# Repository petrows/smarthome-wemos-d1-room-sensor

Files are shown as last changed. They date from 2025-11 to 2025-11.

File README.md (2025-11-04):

# GALOPED: Simple room sensor, Tasmota-ready

Device image

This project designed to provide some simple-to-repeat, WiFi DIY sensor with features:

* Telemetry to Smarthome systems: CO2 level, Temperature, Humidity and Pressure
* Runs Tasmota out-of-the-box, no DIY firmware required, all Tasmota features are on place (WebUI, MQTT, etc)
* Uses cheap Wemos-D1 board as CPU and WiFi
* Do not require SMD components installation, can be assembled with regural solder
* Simple construction, can be used as learning project
* Powered by USB from module (you can use variants with USB-C or Mini USB)
* Optional external power via terminal block
* Uses hi-precision climate sensor module
* Has three LED's, can bu used to display current CO2 level, as well as for any other purpose

## Assembly

What you need to build this device:

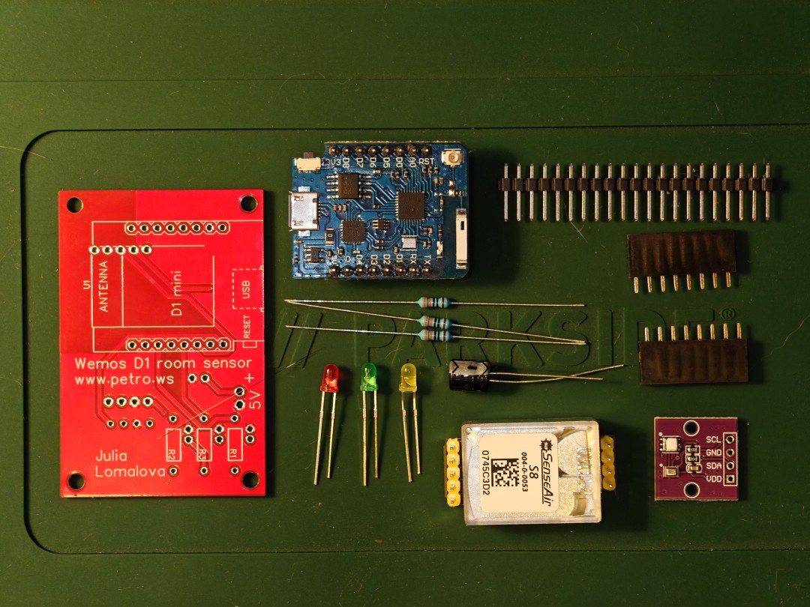
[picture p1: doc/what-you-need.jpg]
What you need


[Detailed assembly instructions](README.Assembly.md).

Required components are:

* PCB board (TBD), ~2€
* Wemos D1 mini / pro board. You can use any kind of this device, using USB-C or classical Mini-USB, [Aliexpress](https://de.aliexpress.com/item/1005001621784437.html), ~5€
* SenseAIR S8 device, original or any of its clones, [Aliexpress](https://de.aliexpress.com/item/1005004123170360.html), ~30€
* AHT20+BMP280 Temperature Humidity Air Pressure Module, [Aliexpress](https://de.aliexpress.com/item/1005005486181411.html), ~3€
* 330R wired resistors, 3 pcs, ~1€
* 3mm LED's, color on your with, 3 pcs, ~1€
* Electrolytic capacitor, suitable any rated 10+ V and 300+ Mf, ~1€
* Common 2.54mm pin headers: male and female, ~1€

Total components price: ~44€

All elements, except MCU and PCB borad are *optional*. Device can be also assembled as CO²-only or Temperature-only device, with and without indication, as well as bare MCU on board. Missing components will not prevent device to run normally, in case of missing components you will not get telemetry data.

**Board is designed to fit into standart 60x60 mm electric box**. I use it at my home to meausre outside temperature (CO² sensor and LED's are not installed).

Electric box version

## PCB Borad

Hardware project page: https://oshwlab.com/petrows/wemos-d1-room-sensor

PCB can be purchased directly from Project page.

## Firmware

Download here: https://github.com/petrows/smarthome-galoped/releases

Regarding flashing / config / recompile: see below

## Case

There is a case for 3D print provided. Files can be found under `3d-case` folder. Model published on [thingiverse.com website](https://www.thingiverse.com/thing:7191151).

> **WARNING**: to use this device within closed case, check and apply calibration. ESP and S8 sensors going warm during work, and it will affect tempterature sensor.

Recommended calibration for this case: `-4 C°`. To apply calibration, navigate to `Console` and type in command:

```
TempOffset -4
```

It is anyway recommended to calibrate your sensor, especially if purchasing some random components on Aliexpress.

## Led display level

LED's are actually GPIO's (connected as Relays in Tasmota), can be triggered via API / MQTT / etc as usial switches.

Provided firmware (see below) has rule activated by default. You may activate it by calling commands:

```
Rule1 "ON S8#CarbonDioxide<800 DO Power3 1 BREAK ON S8#CarbonDioxide<1500 DO Power2 1 BREAK ON S8#CarbonDioxide>0 DO Power1 1 ENDON"
Rule1 ON
```

This will enable fully offline LED indication. In default rules, they will display GREEN below 800, YELLOW below 1500 and RED otherwise. You can find and adjust this levels in `Rule1` command.

If you dont need this rule, you can deactivate it via:

```
Rule1 OFF
```

## Tasmota config

To configure module, you have to use custom firmware, as Tasmota has ANTx sensors support [disabled by default](https://tasmota.github.io/docs/AHT2x/).

Simple workflow to upload proper firmware:

```bash
wget https://petro.ws/s/tasmota-15.1.0-pws-module-v2.bin -O tasmota.bin
esptool erase_flash
esptool write_flash -fm dout 0x0 tasmota.bin
```

Then configure Tasmota as usial, by connecting to built-in WiFI AP.

Next step is to apply template. Navigate to `Configuration` » `Other`. There in `Template` section paste template:
```json
{"NAME":"PWS-Room-v2","GPIO":[1,1,1,1,608,640,1,1,224,1632,225,1600,226,1],"FLAG":0,"BASE":18,"CMND":"Interlock 1|WebButton1 R | WebButton2 Y | WebButton3 G | Rule1 ON"}
```
Enable `Activate` checkbox. Press `Save` to apply template.

Connect you sensors back and now you will see data from sensors read:

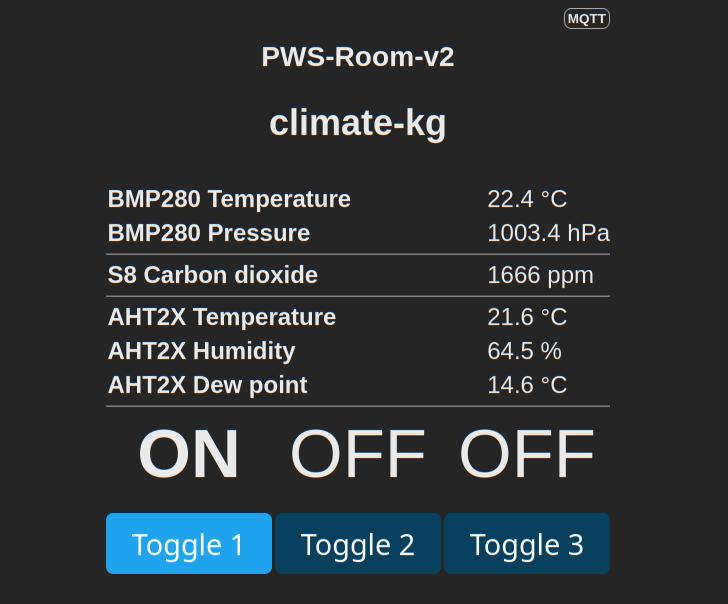
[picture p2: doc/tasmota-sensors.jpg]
Sensors data example


## Compile firmware

Prepare environment first.
Note: important to use same console, as it uses virtual environment activated.
All commands should be executed from repo root.

```bash
# Prepare Python env
python -m venv build/venv
source build/venv/bin/activate
# Install PlatformIO
pip install -U platformio
git clone https://github.com/arendst/Tasmota.git build/tasmota
```

Select release, what you want to use as a base:
```bash
cd build/tasmota
git checkout v15.1.0
```

Copy overrides config, where we have proper sensors enabled:
```bash
cp user_config_override.h build/tasmota/tasmota/
```

Now you can compile firmware. Replace upload port with your own:
```bash
cd build/tasmota
platformio run -e tasmota --target upload --upload-port /dev/ttyUSB0
```

Precompiled firmware can be found under `.pio/build/tasmota/firmware.bin`.

Precompiled firmwares could be found here: https://github.com/petrows/smarthome-galoped/releases

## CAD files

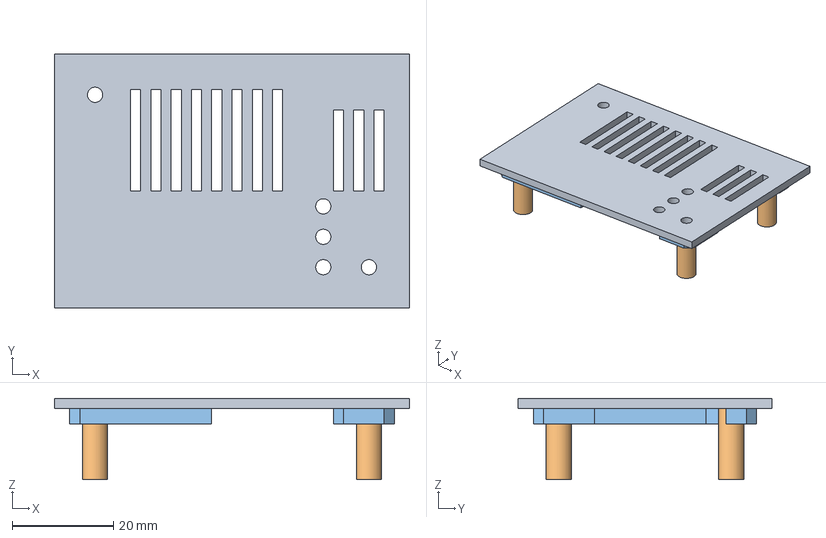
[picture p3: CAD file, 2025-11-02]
3d-case/smarthome-wemos-d1-room-sensor-case-up.FCStd
70.0 x 50.0 x 16.0 mm
Holders

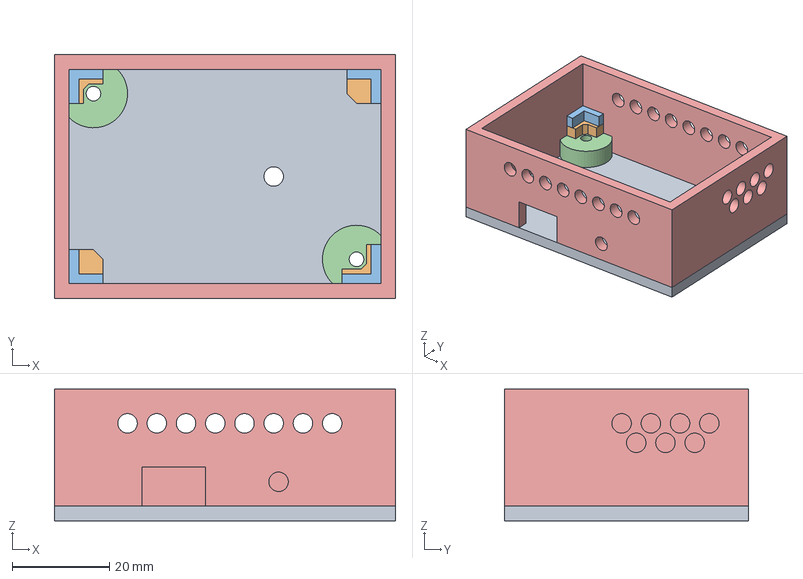
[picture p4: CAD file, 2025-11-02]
3d-case/smarthome-wemos-d1-room-sensor-case-down.FCStd
70.0 x 50.0 x 27.0 mm
Bottom
Board-support
Board-corners001
Nuts-base001

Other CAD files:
3d-case/smarthome-wemos-d1-room-sensor-case-board.FCStd
3d-case/smarthome-wemos-d1-room-sensor-case-down.stl
3d-case/smarthome-wemos-d1-room-sensor-case-up.stl

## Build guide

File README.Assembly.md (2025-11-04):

# Assembly instructions

First, prepare what you need:

What you need

## PCB passive components assembly

First of all, select *female* pinheads and cut off them to: 2x 4-pin and 1x 5-pin.

Solder them to marked places into S8 and ANT20 modules as folows:

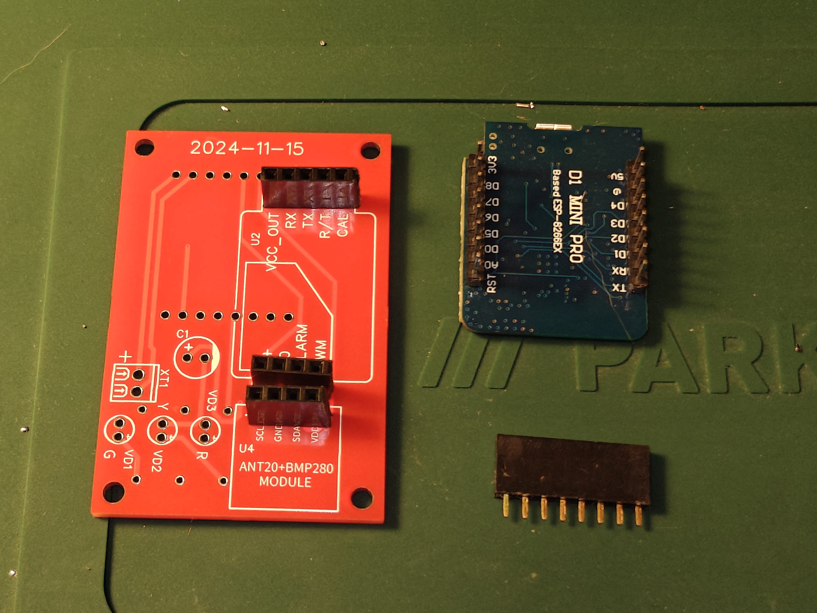
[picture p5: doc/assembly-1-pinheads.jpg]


**WARNING**: Test your solder quality with tester! Futher fixes will be hard to do, as solder points will be covered by MCU on next steps!

Install capacitor on the marked place:

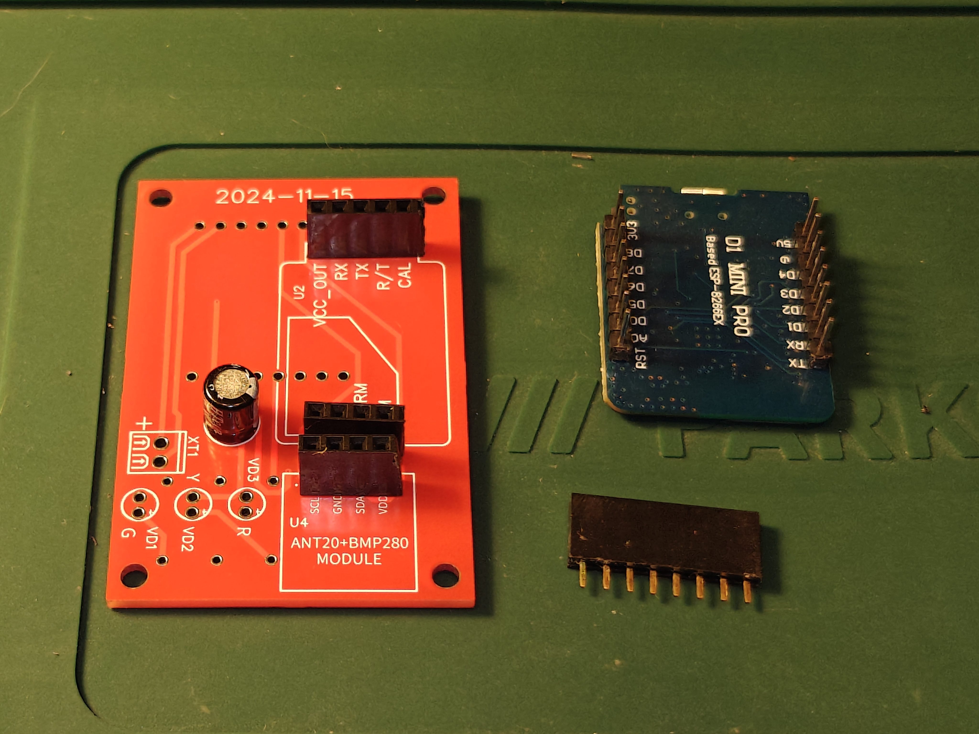
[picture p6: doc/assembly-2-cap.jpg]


Install LED limiting resisors on the marked place:

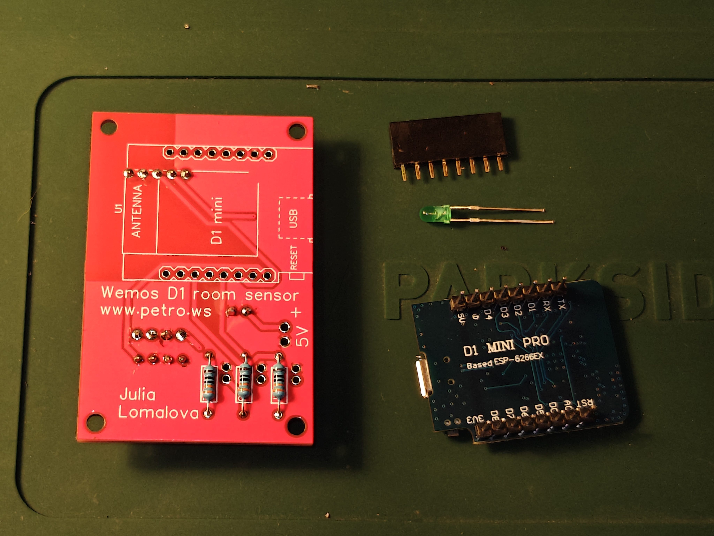
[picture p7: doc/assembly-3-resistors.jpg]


Prepare LED's. To use within provided case, they have to be with 13 mm offcet from board. One of possible way to fit this distance: cut off the isolation tube in advance, and use it on install:

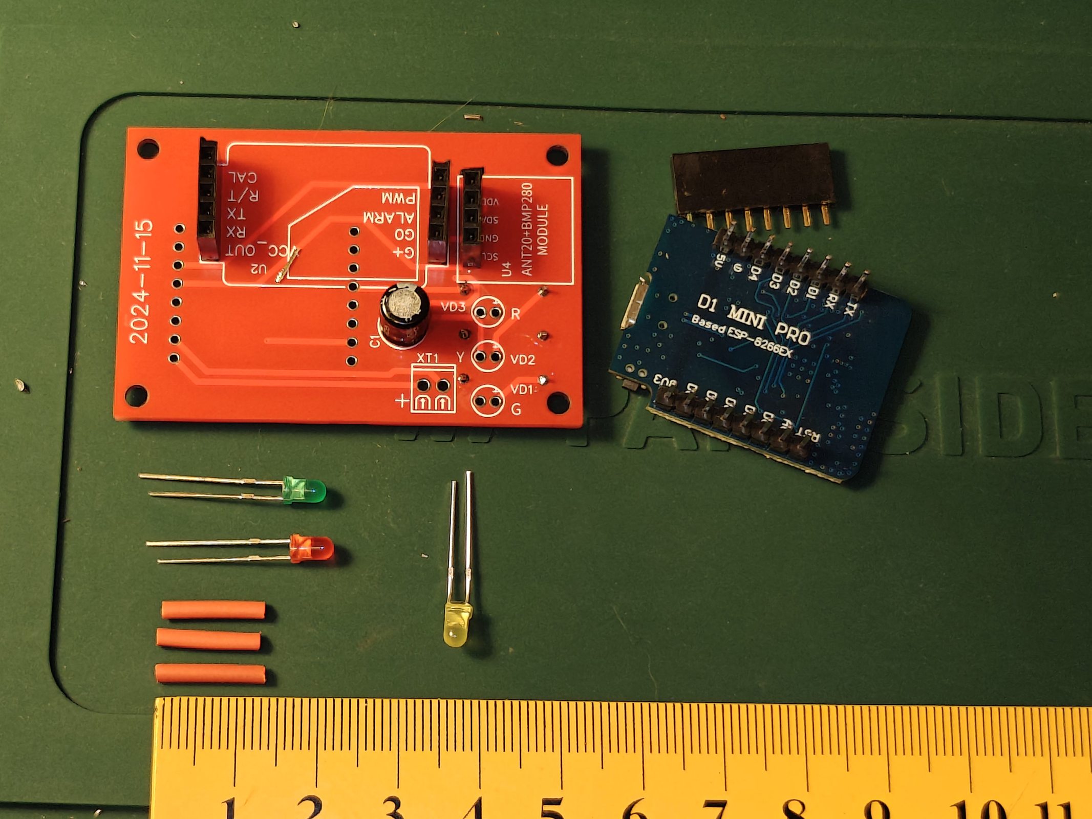
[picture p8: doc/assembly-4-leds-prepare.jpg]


Using isolation tube is optional, you can solder LED's directly, but this makes installation easier:

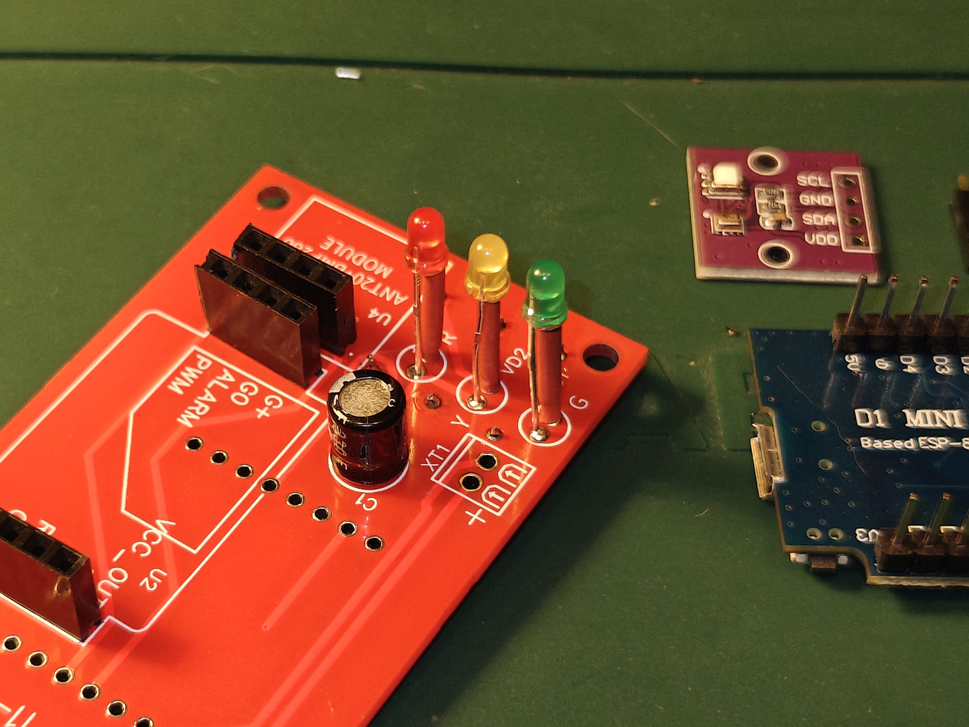
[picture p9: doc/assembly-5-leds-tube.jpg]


## MCU module

It is time to prepare your MCU!

Solder the *male* pinheads, usially included with Wemos D1. Then it is recommended to upload and test firmware:

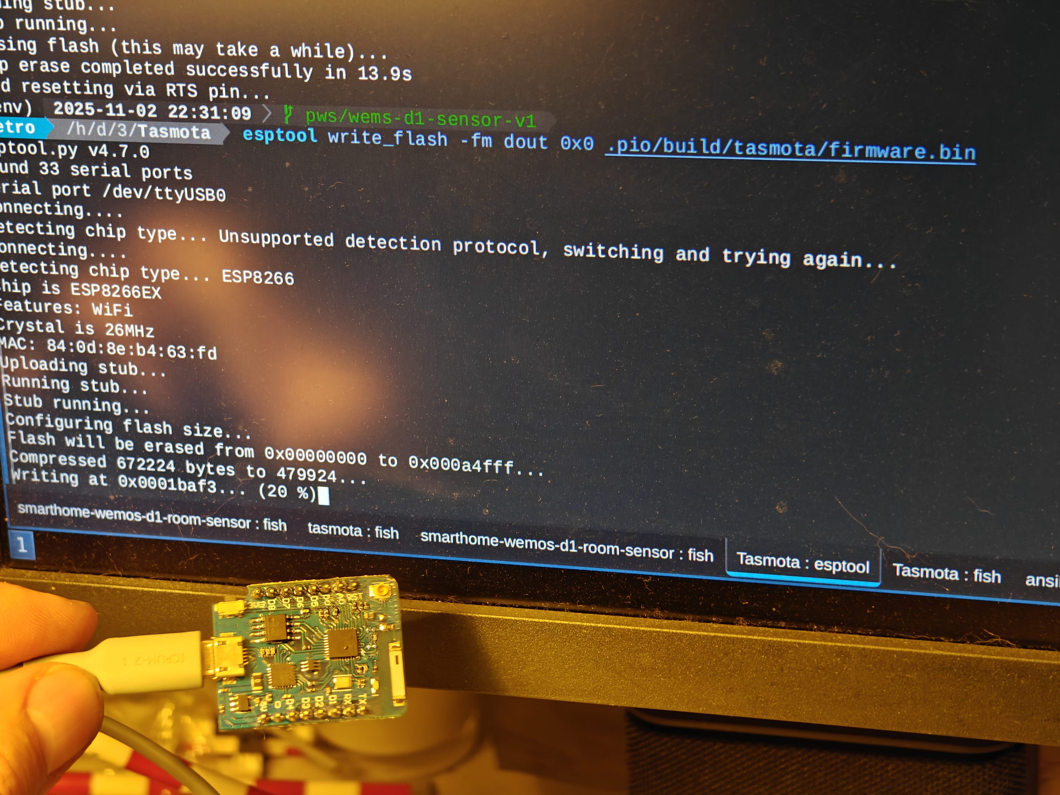
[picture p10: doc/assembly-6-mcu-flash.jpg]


It is important to have MCU tested, before it is soldered. Futher replacement will be hard.

Upon tested, solder MCU on the board, using double-side *male* pinheads.

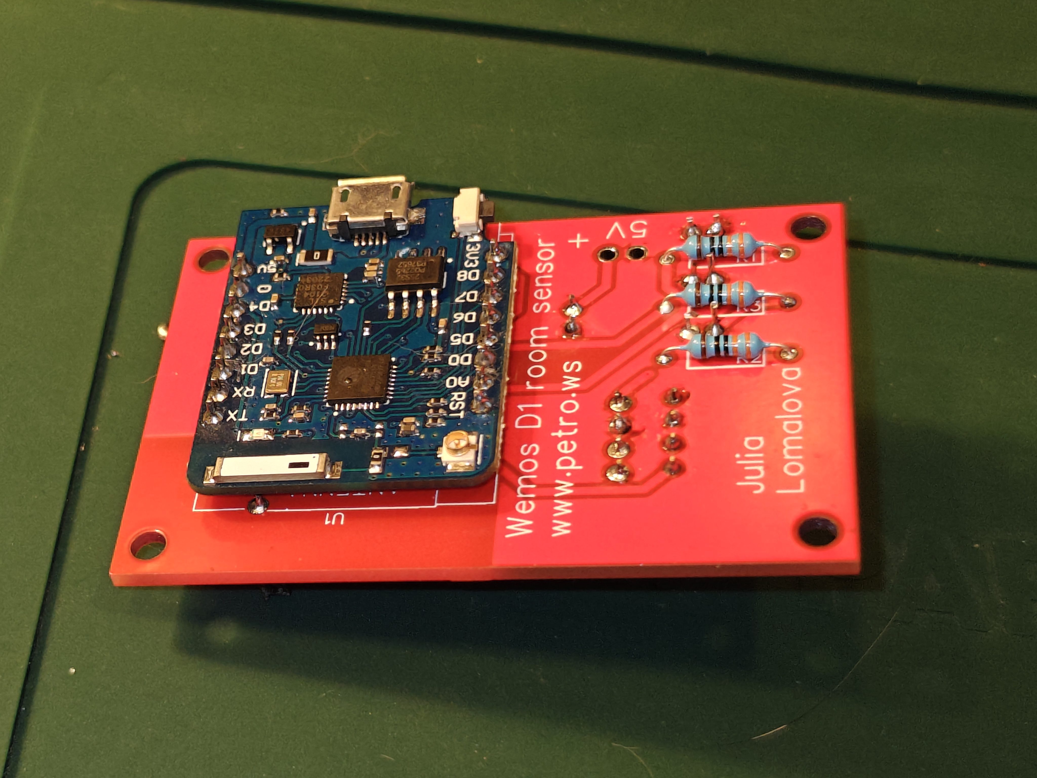
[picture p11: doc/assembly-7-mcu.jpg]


Check that there is nothing contacts between board and MCU:

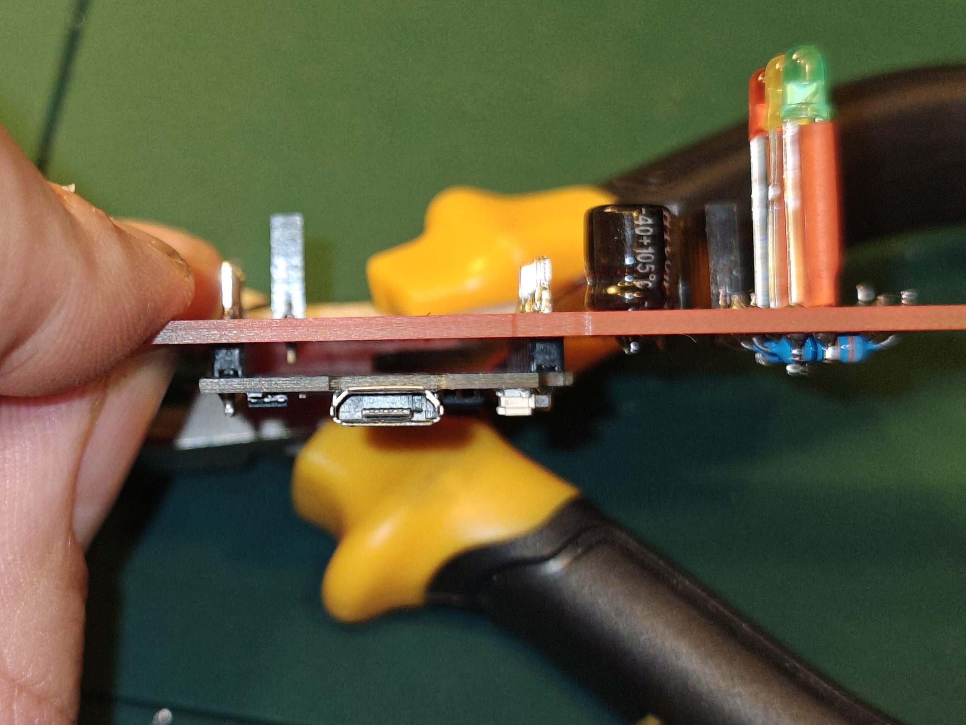
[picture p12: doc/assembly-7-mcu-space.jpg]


MCU installation is done.

## Final assembly

Solder pinheads on sensors (if you dont have them preinstalled). Avare of the right orientation of board side:

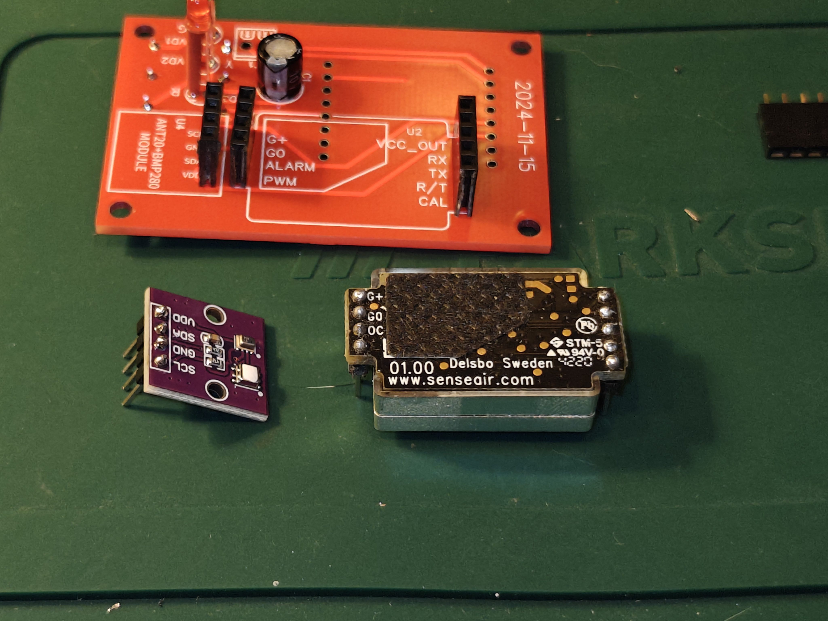
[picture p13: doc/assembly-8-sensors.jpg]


SenseAir S8 **must** be oriented with covered hole and PCB up. Recheck and install modules on board:

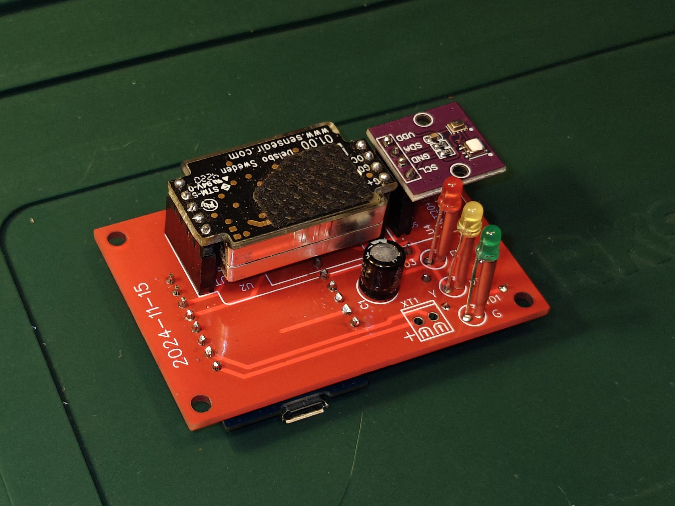
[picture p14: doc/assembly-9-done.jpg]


Device is complete! Please enjoy :-)

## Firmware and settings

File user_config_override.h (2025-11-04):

/*
  user_config_override.h - user configuration overrides my_user_config.h for Tasmota

  Copyright (C) 2021  Theo Arends

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
  You should have received a copy of the GNU General Public License
  along with this program.  If not, see <http://www.gnu.org/licenses/>.
*/

#ifndef _USER_CONFIG_OVERRIDE_H_
#define _USER_CONFIG_OVERRIDE_H_

/*****************************************************************************************************\
 * USAGE:
 *   To modify the stock configuration without changing the my_user_config.h file:
 *   (1) copy this file to "user_config_override.h" (It will be ignored by Git)
 *   (2) define your own settings below
 *
 ******************************************************************************************************
 * ATTENTION:
 *   - Changes to SECTION1 PARAMETER defines will only override flash settings if you change define CFG_HOLDER.
 *   - Expect compiler warnings when no ifdef/undef/endif sequence is used.
 *   - You still need to update my_user_config.h for major define USE_MQTT_TLS.
 *   - All parameters can be persistent changed online using commands via MQTT, WebConsole or Serial.
\*****************************************************************************************************/

/*
Examples :

// -- Master parameter control --------------------
#undef  CFG_HOLDER
#define CFG_HOLDER        4617                   // [Reset 1] Change this value to load SECTION1 configuration parameters to flash

// -- Setup your own Wifi settings  ---------------
#undef  STA_SSID1
#define STA_SSID1         "YourSSID"             // [Ssid1] Wifi SSID

#undef  STA_PASS1
#define STA_PASS1         "YourWifiPassword"     // [Password1] Wifi password

// -- Setup your own MQTT settings  ---------------
#undef  MQTT_HOST
#define MQTT_HOST         "your-mqtt-server.com" // [MqttHost]

#undef  MQTT_PORT
#define MQTT_PORT         1883                   // [MqttPort] MQTT port (10123 on CloudMQTT)

#undef  MQTT_USER
#define MQTT_USER         "YourMqttUser"         // [MqttUser] Optional user

#undef  MQTT_PASS
#define MQTT_PASS         "YourMqttPass"         // [MqttPassword] Optional password

// You might even pass some parameters from the command line ----------------------------
// Ie:  export PLATFORMIO_BUILD_FLAGS='-DUSE_CONFIG_OVERRIDE -DMY_IP="192.168.1.99" -DMY_GW="192.168.1.1" -DMY_DNS="192.168.1.1"'

#ifdef MY_IP
#undef  WIFI_IP_ADDRESS
#define WIFI_IP_ADDRESS     MY_IP                // Set to 0.0.0.0 for using DHCP or enter a static IP address
#endif

#ifdef MY_GW
#undef  WIFI_GATEWAY
#define WIFI_GATEWAY        MY_GW                // if not using DHCP set Gateway IP address
#endif

#ifdef MY_DNS
#undef  WIFI_DNS
#define WIFI_DNS            MY_DNS               // If not using DHCP set DNS IP address (might be equal to WIFI_GATEWAY)
#endif

#ifdef MY_DNS2
#undef  WIFI_DNS2
#define WIFI_DNS2           MY_DNS2              // If not using DHCP set DNS IP address (might be equal to WIFI_GATEWAY)
#endif

// !!! Remember that your changes GOES AT THE BOTTOM OF THIS FILE right before the last #endif !!!
*/

// Activate used sensors: ANT2X, BMP and SENSEAIR S8
#define USE_BMP
#define USE_AHT2x
#define USE_SENSEAIR

// My template defaults, apply on flash reset.
// You may skip this templay application, in this case please apply manually (see README.md)
#define USER_TEMPLATE "{\"NAME\":\"PWS-Room-v2\",\"GPIO\":[1,1,1,1,608,640,1,1,224,1632,225,1600,226,1],\"FLAG\":0,\"BASE\":18,\"CMND\":\"Interlock 1|WebButton1 R | WebButton2 Y | WebButton3 G | Rule1 ON\"}"
// Activate template on reset/flash new
#define MODULE USER_MODULE

// Basic rules to control the RGB LED based on CO2 levels
#define CO_LEVEL_YELLOW "800"
#define CO_LEVEL_RED "1500"
// Define rule:
#define USER_RULE1 "ON S8#CarbonDioxide<" CO_LEVEL_YELLOW " DO Power3 1 BREAK ON S8#CarbonDioxide<" CO_LEVEL_RED " DO Power2 1 BREAK ON S8#CarbonDioxide>0 DO Power1 1 ENDON"

#endif  // _USER_CONFIG_OVERRIDE_H_

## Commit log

2025-11-04 Update README, assembly and PCB stub
2025-11-04 Update README, assembly steps done

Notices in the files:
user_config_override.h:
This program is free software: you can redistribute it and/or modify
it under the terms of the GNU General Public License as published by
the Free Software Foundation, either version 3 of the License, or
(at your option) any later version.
